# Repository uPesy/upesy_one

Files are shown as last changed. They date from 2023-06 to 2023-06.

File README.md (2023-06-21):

# uPesy One Board

In this repository you'll find Kicad 7.0 design files, BOM, schematics, 3D models for the uPesy One board. An Arduino UNO compatible board based on the ATMEGA328PB chip.

<p align="center">
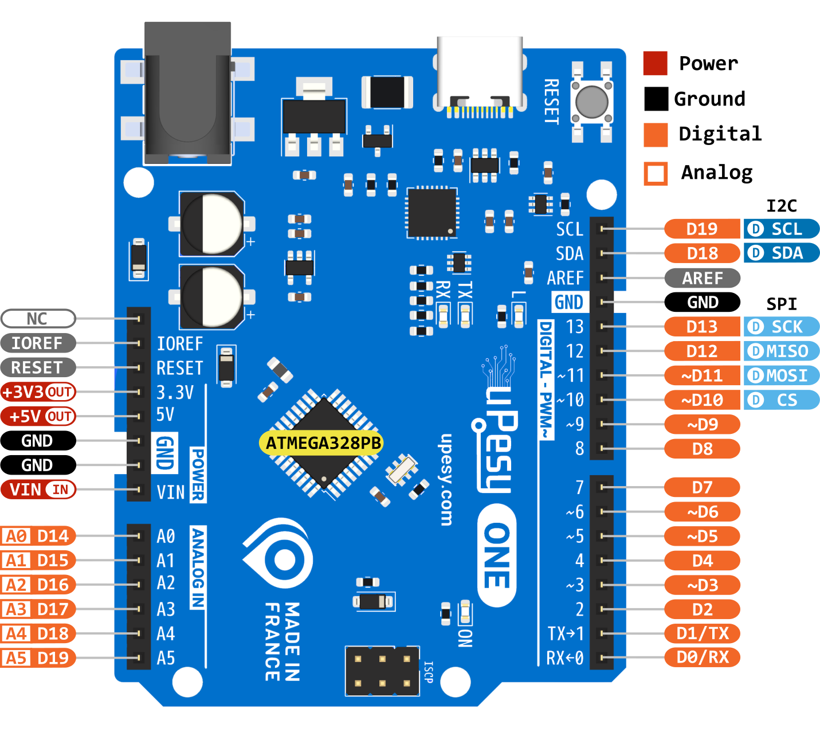
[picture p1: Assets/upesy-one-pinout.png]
  
</p>

## 🙏 Contribute

Feel free to suggest improvements and report any bugs you encounter by submitting a PR or an issue :)

## ⚖️ License

The uPesy One board files are licensed under the [Creative Commons CC-BY-SA 4.0 License](https://creativecommons.org/licenses/by-sa/4.0/legalcode).

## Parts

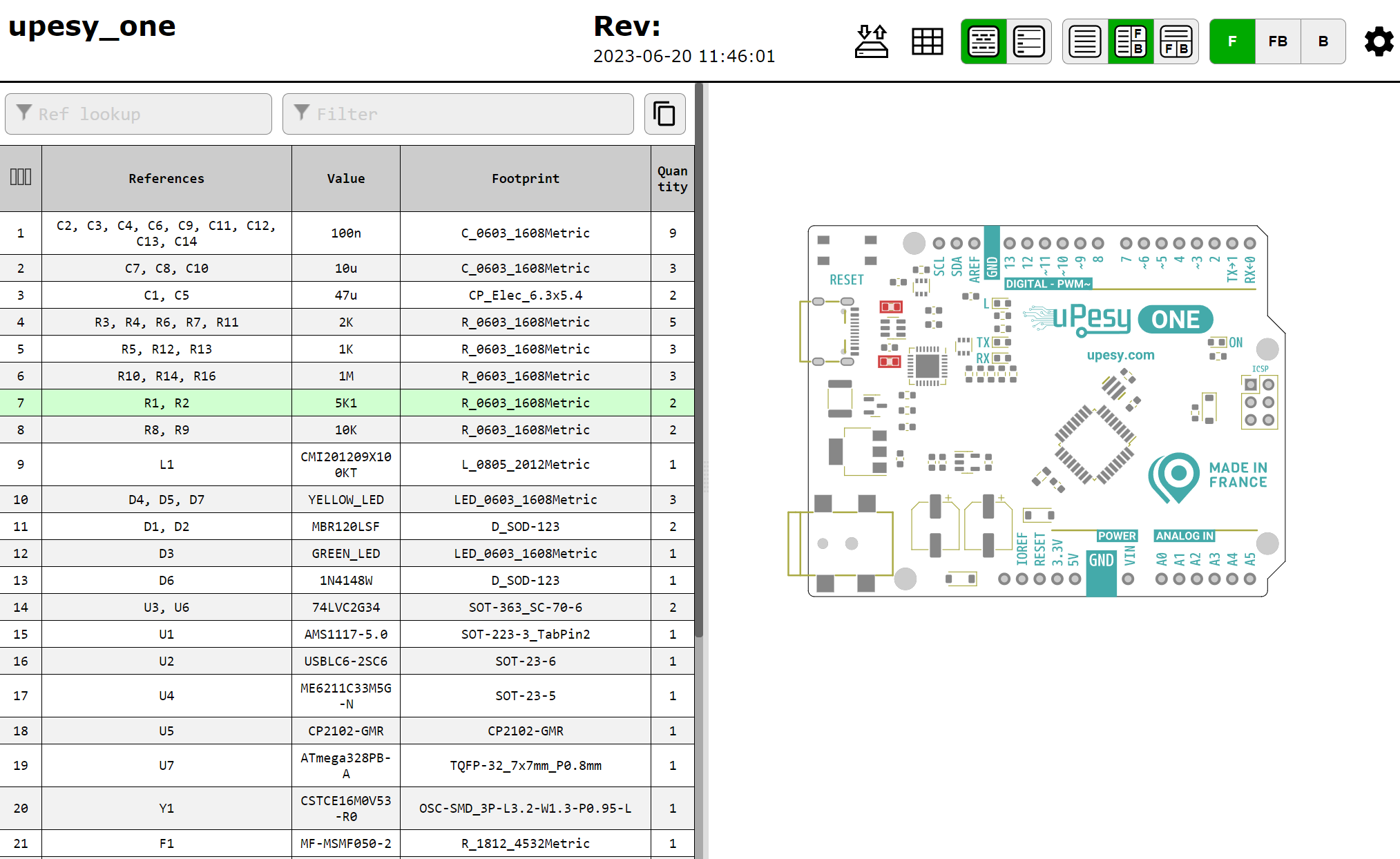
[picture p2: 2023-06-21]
Assets/screenshot_bom.PNG

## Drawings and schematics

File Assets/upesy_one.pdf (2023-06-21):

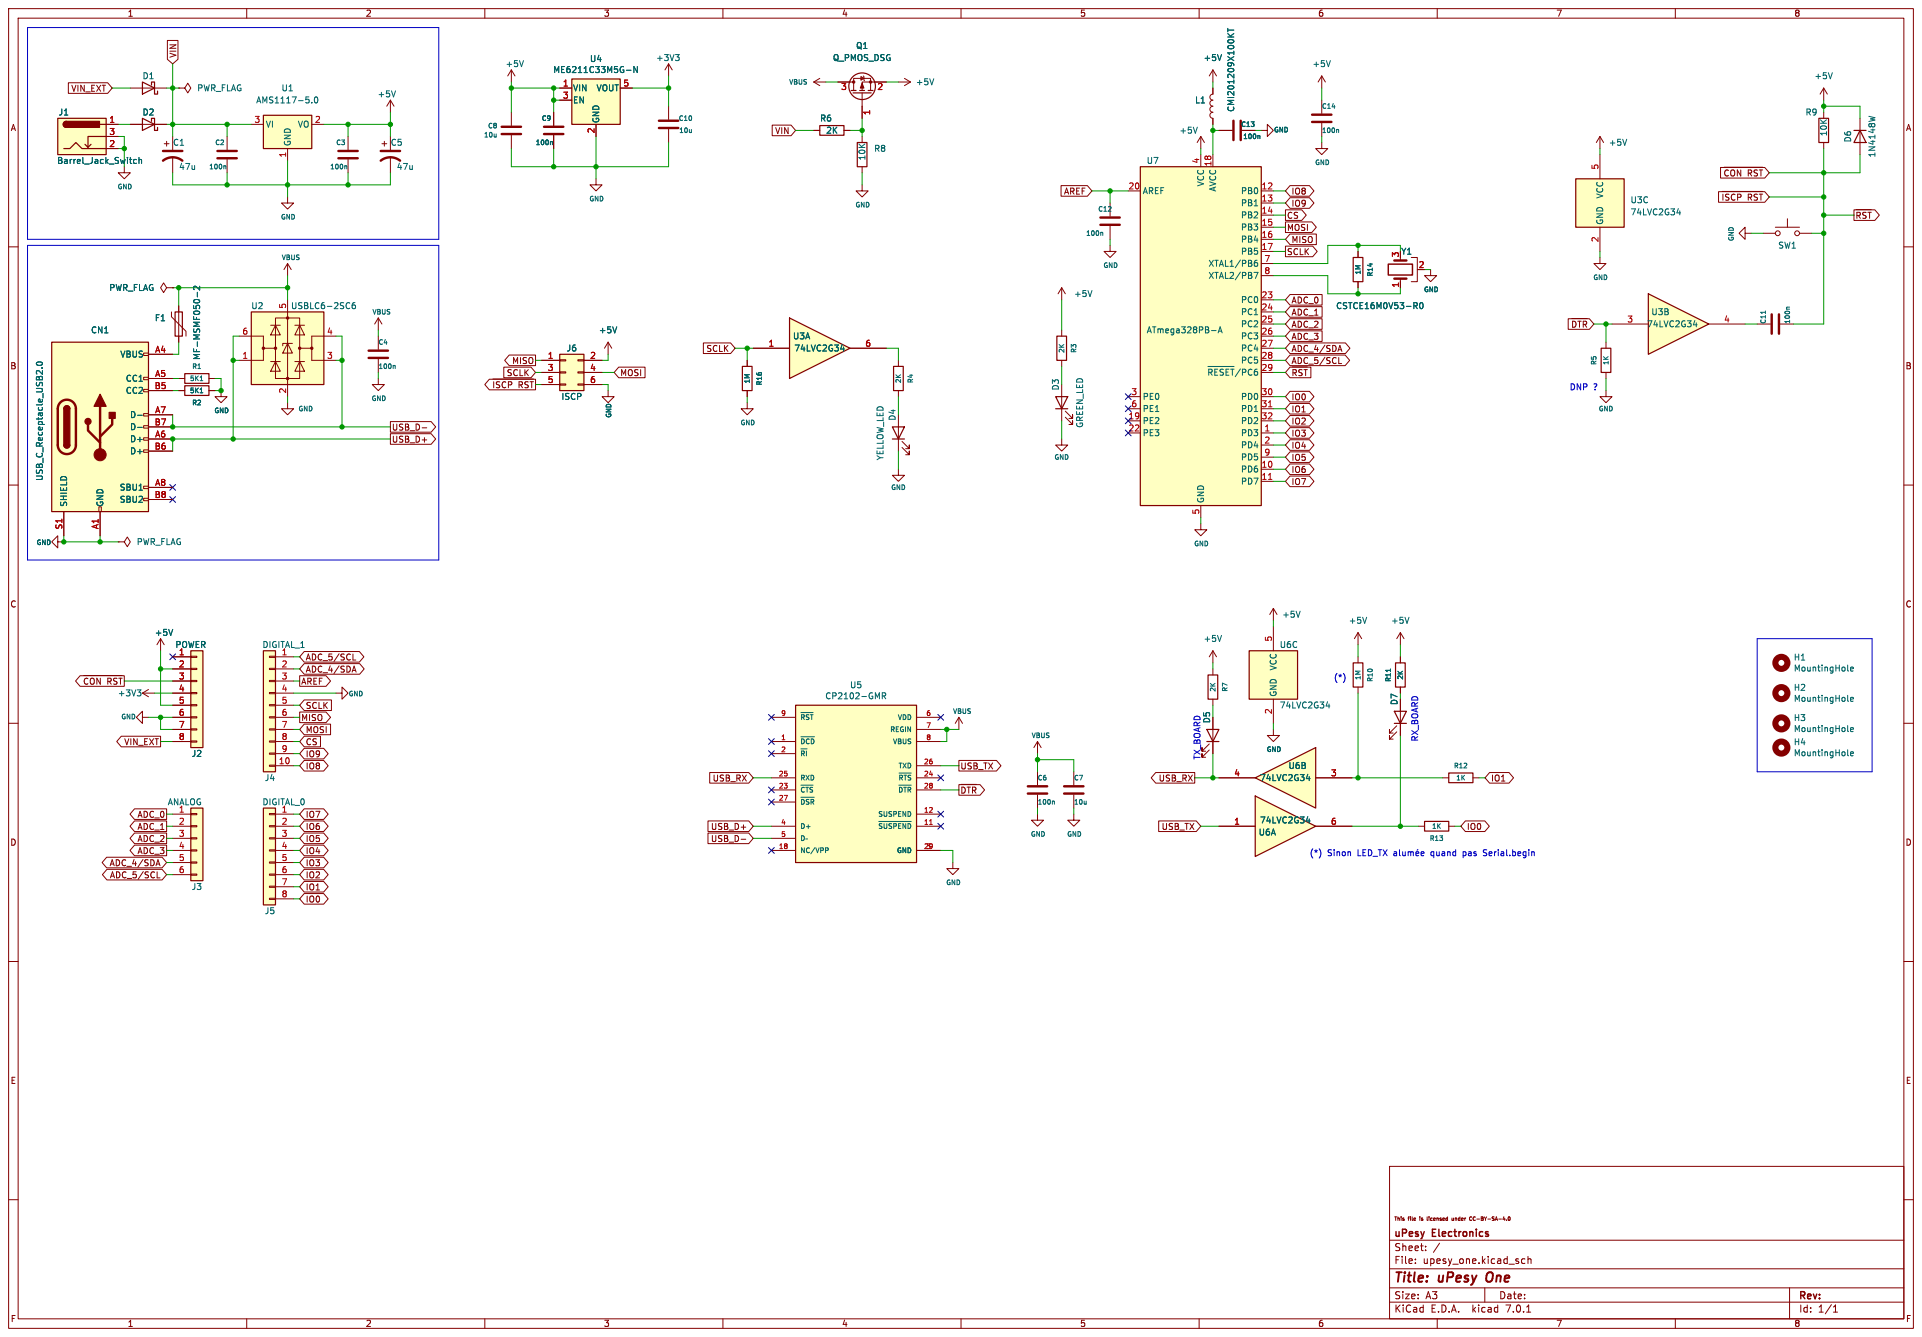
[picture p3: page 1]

(*) Sinon LED_TX þÿalumée quand pas Serial.begin

Id: 1/1 Title: uPesy One

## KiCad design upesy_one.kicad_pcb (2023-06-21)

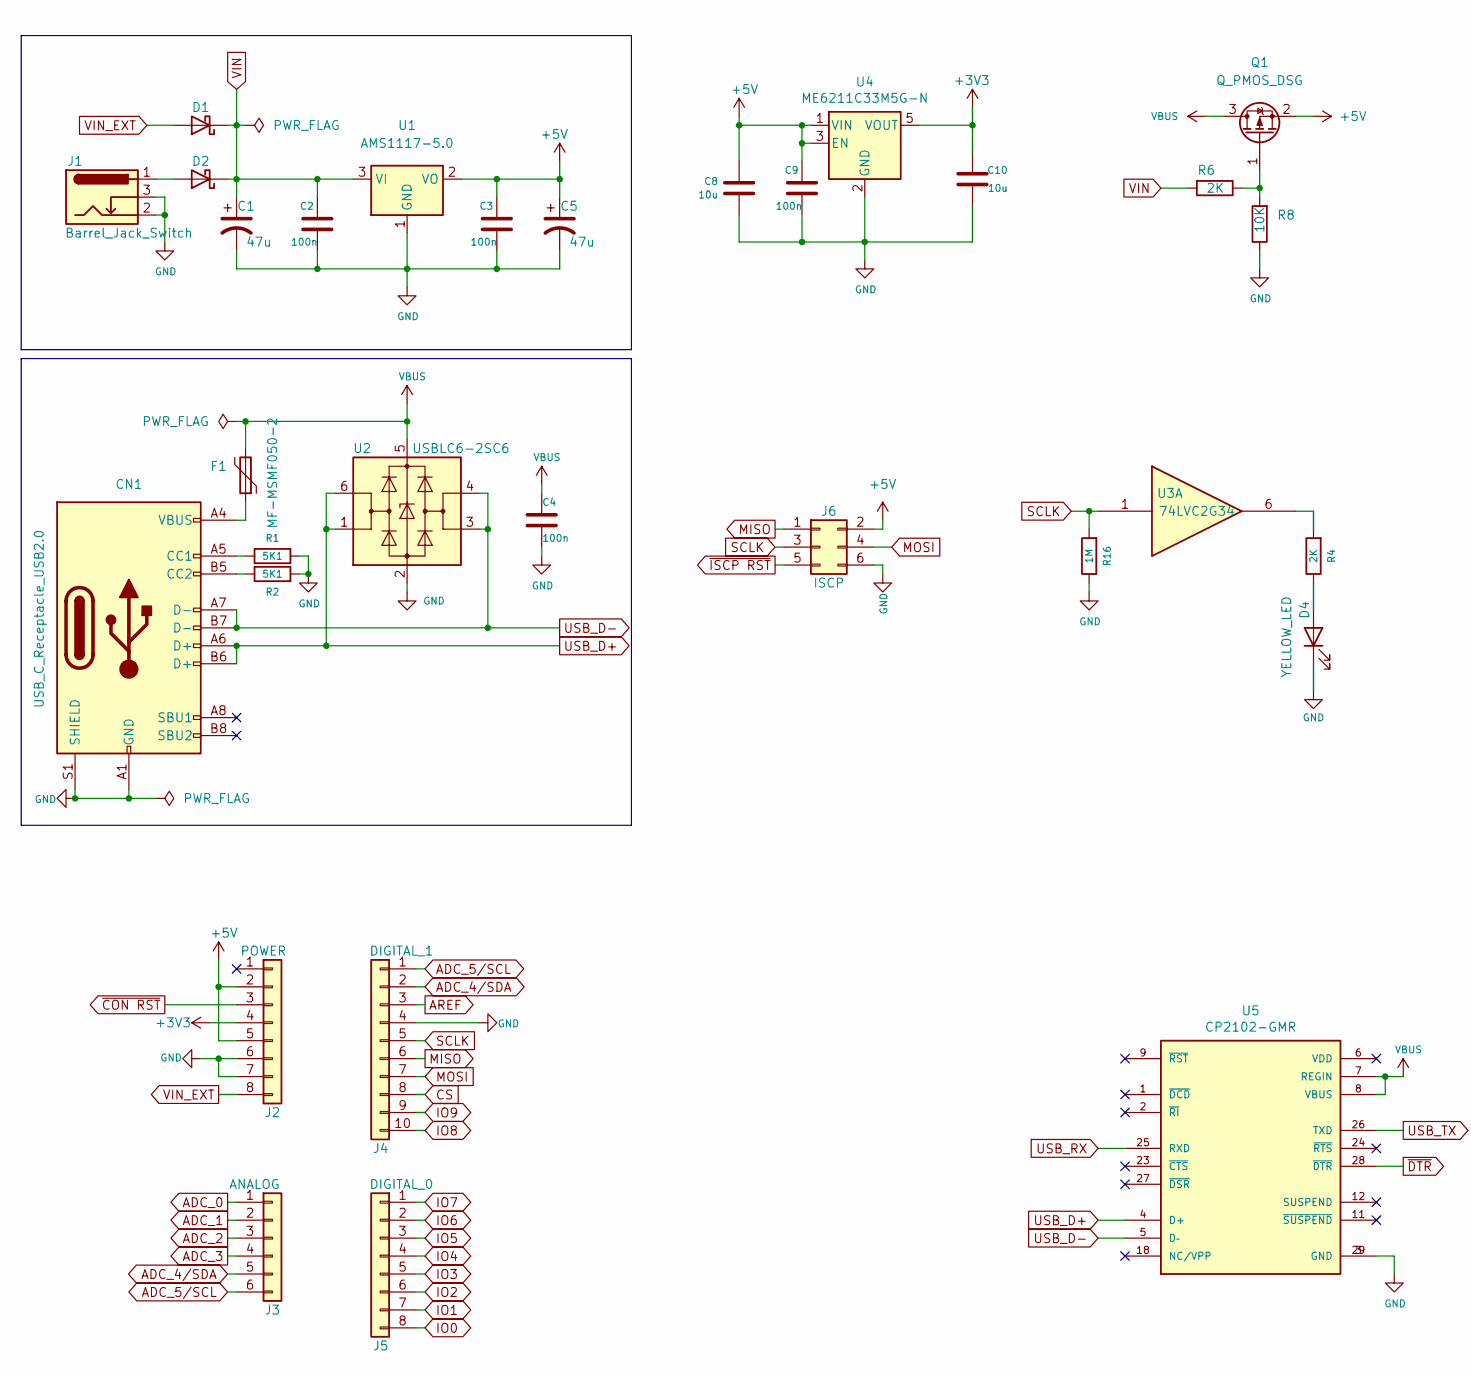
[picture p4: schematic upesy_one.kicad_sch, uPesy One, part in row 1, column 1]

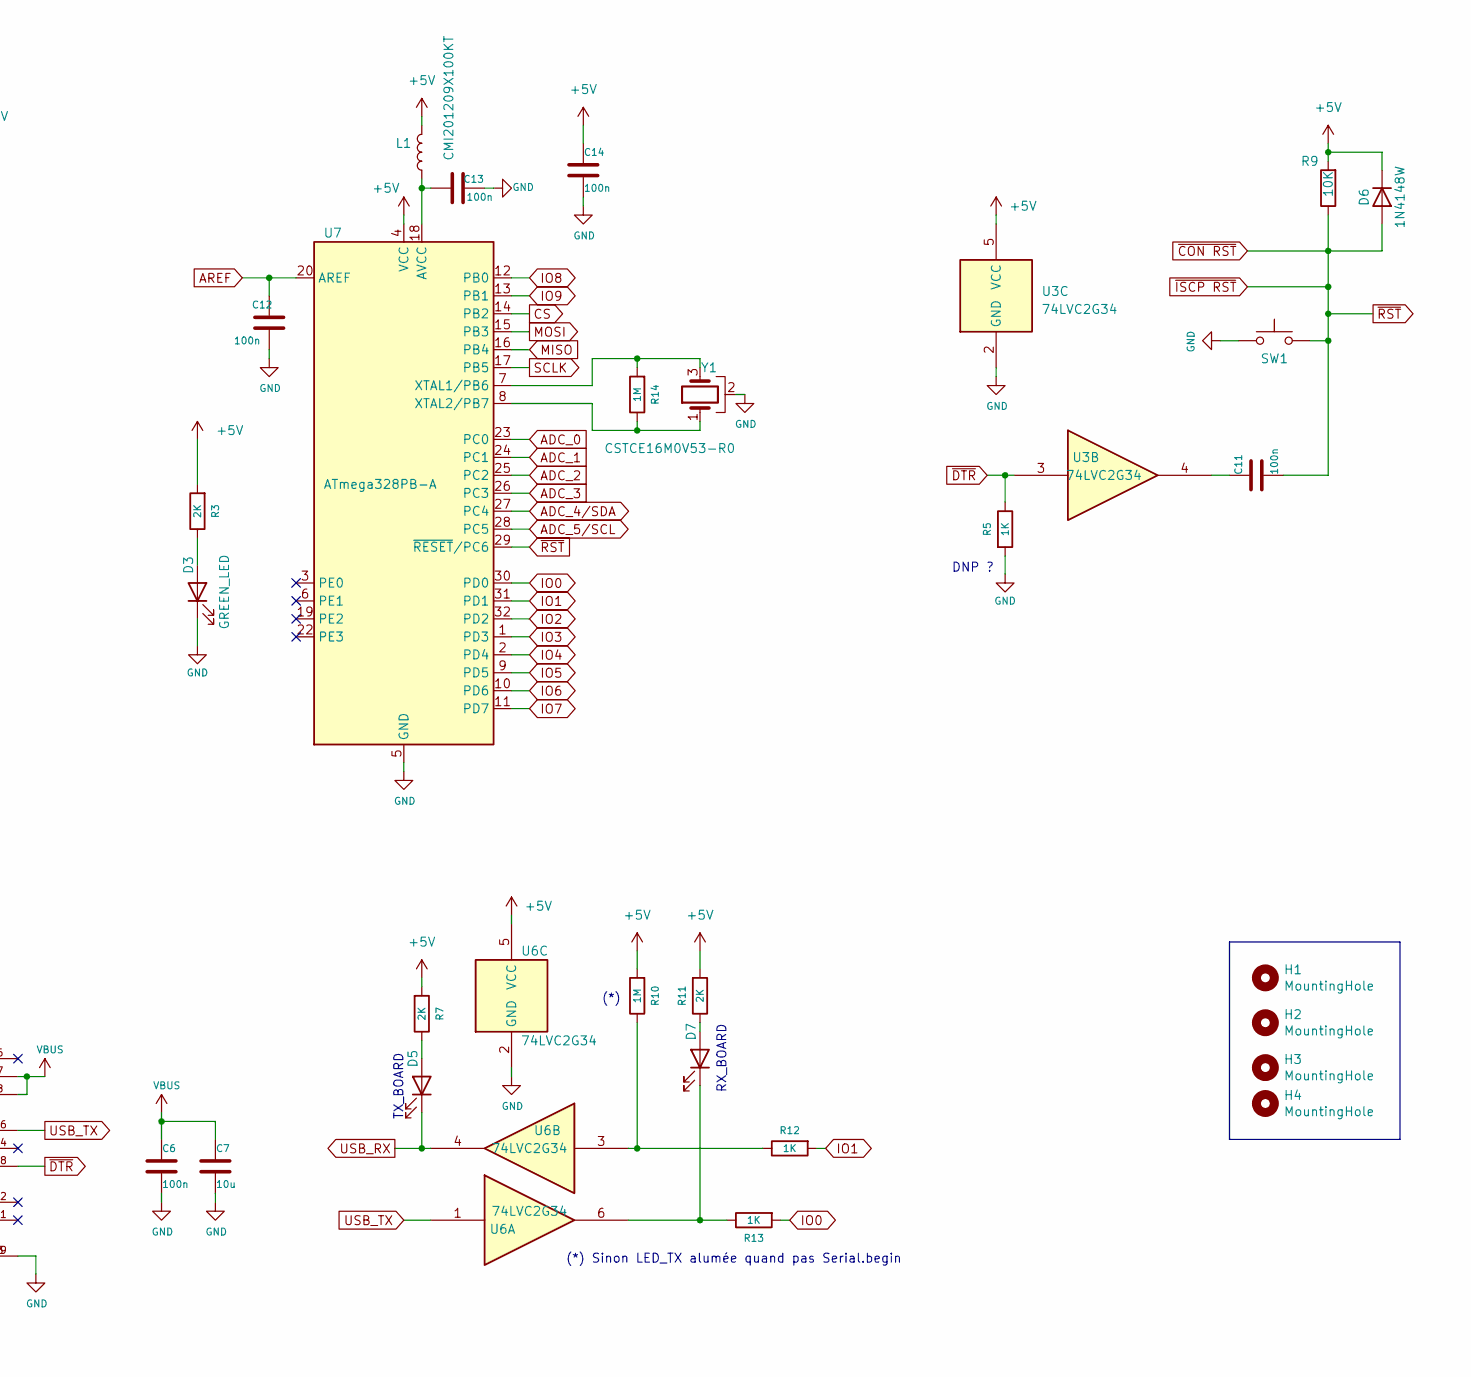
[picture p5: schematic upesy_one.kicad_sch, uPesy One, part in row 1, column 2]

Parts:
C1, C5: 47u; CP_Elec_6.3x5.4
C2, C3, C4, C6, C9, C11, C12, C13, C14: 100n; C_0603_1608Metric
C7, C8, C10: 10u; C_0603_1608Metric
CN1: USB_C_Receptacle_USB2.0; USB_C_C165948
D1, D2: MBR120LSF; D_SOD-123
D3: GREEN_LED; LED_0603_1608Metric
D4, D5, D7: YELLOW_LED; LED_0603_1608Metric
D6: 1N4148W; D_SOD-123
F1: MF-MSMF050-2; R_1812_4532Metric
H1, H2, H3, H4: MountingHole; MountingHole_3.2mm_M3_DIN965
J1: Barrel_Jack_Switch; DC-IN_DC050-T
J2: POWER; PinSocket_1x08_P2.54mm_Vertical
J3: ANALOG; PinSocket_1x06_P2.54mm_Vertical
J4: DIGITAL_1; PinSocket_1x10_P2.54mm_Vertical
J5: DIGITAL_0; PinSocket_1x08_P2.54mm_Vertical
J6: ISCP; PinHeader_2x03_P2.54mm_Vertical
L1: CMI201209X100KT; L_0805_2012Metric
Q1: Q_PMOS_DSG; SOT-23
R1, R2: 5K1; R_0603_1608Metric
R3, R4, R6, R7, R11: 2K; R_0603_1608Metric
R5, R12, R13: 1K; R_0603_1608Metric
R8, R9: 10K; R_0603_1608Metric
R10, R14, R16: 1M; R_0603_1608Metric
SW1: SW_Push; KEY-SMD_4P-L4.5-W4.5-P3.00-LS6.9
U1: AMS1117-5.0; SOT-223-3_TabPin2
U2: USBLC6-2SC6; SOT-23-6
U3, U6: 74LVC2G34; SOT-363_SC-70-6
U4: ME6211C33M5G-N; SOT-23-5
U5: CP2102-GMR
U7: ATmega328PB-A; TQFP-32_7x7mm_P0.8mm
Y1: CSTCE16M0V53-R0; OSC-SMD_3P-L3.2-W1.3-P0.95-L

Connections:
+3V3: C10.2, J2.4, U4.5 (VOUT)
+5V: C3.1, C5.1, C8.2, C9.1, C14.2, D6.1 (K), J2.2, J2.5, J6.2, L1.2, Q1.2 (S), R3.2, R7.2, R9.2, R10.2, R11.2, U1.2 (VO), U3.5 (VCC), U4.1 (VIN), U4.3 (EN), U6.5 (VCC), U7.4 (VCC)
ADC_0: J3.1, U7.23 (PC0)
ADC_1: J3.2, U7.24 (PC1)
ADC_2: J3.3, U7.25 (PC2)
ADC_3: J3.4, U7.26 (PC3)
ADC_4/SDA: J3.5, J4.2, U7.27 (PC4)
ADC_5/SCL: J3.6, J4.1, U7.28 (PC5)
AREF: C12.2, J4.3, U7.20 (AREF)
CS: J4.8, U7.14 (PB2)
GND: C1.2, C2.2, C3.2, C4.1, C5.2, C6.1, C7.2, C8.1, C9.2, C10.1, C12.1, C13.2, C14.1, CN1.A1 (GND), CN1.A12 (GND), CN1.S1 (SHIELD), D3.1 (K), D4.1 (K), J1.2, J1.3, J2.6, J2.7, J4.4, J6.6, R1.2, R2.2, R5.2, R8.1, R16.1, SW1.1, U1.1 (GND), U2.2 (GND), U3.2 (GND), U4.2 (GND), U5.3 (GND), U5.29 (GND), U6.2 (GND), U7.5 (GND), U7.21 (GND), Y1.2
IO0: J5.8, R13.2, U7.30 (PD0)
IO1: J5.7, R12.2, U7.31 (PD1)
IO2: J5.6, U7.32 (PD2)
IO3: J5.5, U7.1 (PD3)
IO4: J5.4, U7.2 (PD4)
IO5: J5.3, U7.9 (PD5)
IO6: J5.2, U7.10 (PD6)
IO7: J5.1, U7.11 (PD7)
IO8: J4.10, U7.12 (PB0)
IO9: J4.9, U7.13 (PB1)
MISO: J4.6, J6.1, U7.16 (PB4)
MOSI: J4.7, J6.4, U7.15 (PB3)
unnamed: C11.2, U3.4
unnamed: CN1.A5 (CC1), R1.1
unnamed: CN1.B5 (CC2), R2.1
unnamed: CN1.A4 (VBUS), CN1.A9 (VBUS), F1.1
unnamed: D2.2 (A), J1.1
unnamed: D3.2 (A), R3.1
unnamed: D4.2 (A), R4.1
unnamed: D5.2 (A), R7.1
unnamed: D7.2 (A), R11.1
unnamed: D7.1 (K), R13.1, U6.6
unnamed: Q1.1 (G), R6.1, R8.2
unnamed: R4.2, U3.6
unnamed: R10.1, R12.1, U6.3
unnamed: C13.1, L1.1, U7.18 (AVCC)
unnamed: R14.2, U7.7 (XTAL1/PB6), Y1.3
unnamed: R14.1, U7.8 (XTAL2/PB7), Y1.1
SCLK: J4.5, J6.3, R16.2, U3.1, U7.17 (PB5)
USB_D+: CN1.A6 (D+), CN1.B6 (D+), U2.1 (I/O1), U2.6 (I/O1), U5.4 (D+)
USB_D-: CN1.A7 (D-), CN1.B7 (D-), U2.3 (I/O2), U2.4 (I/O2), U5.5 (D–)
USB_RX: D5.1 (K), U5.25 (RXD), U6.4
USB_TX: U5.26 (TXD), U6.1
VBUS: C4.2, C6.2, C7.1, F1.2, Q1.3 (D), U2.5 (VBUS), U5.7 (REGIN), U5.8 (VBUS)
VIN: C1.1, C2.1, D1.1 (K), D2.1 (K), R6.2, U1.3 (VI)
VIN_EXT: D1.2 (A), J2.8
~CON RST: C11.1, D6.2 (A), J2.3, J6.5, R9.1, SW1.2, U7.29 (~RESET/PC6)
~DTR: R5.1, U3.3, U5.28 (~DTR)

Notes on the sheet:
TX_BOARD
(*) Sinon LED_TX alumée quand pas Serial.begin
RX_BOARD
(*)
DNP ?

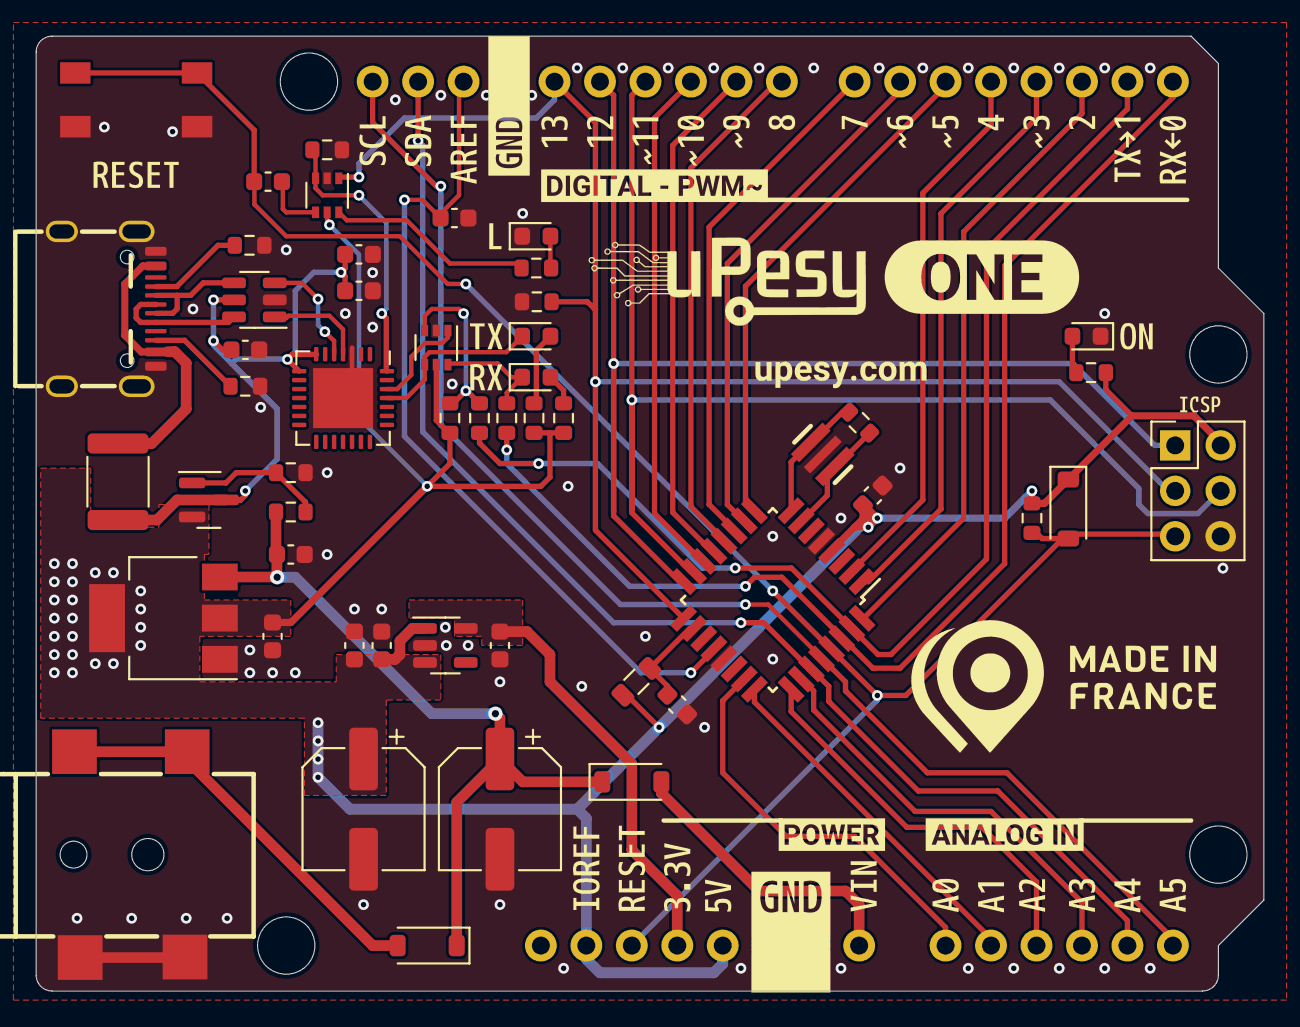
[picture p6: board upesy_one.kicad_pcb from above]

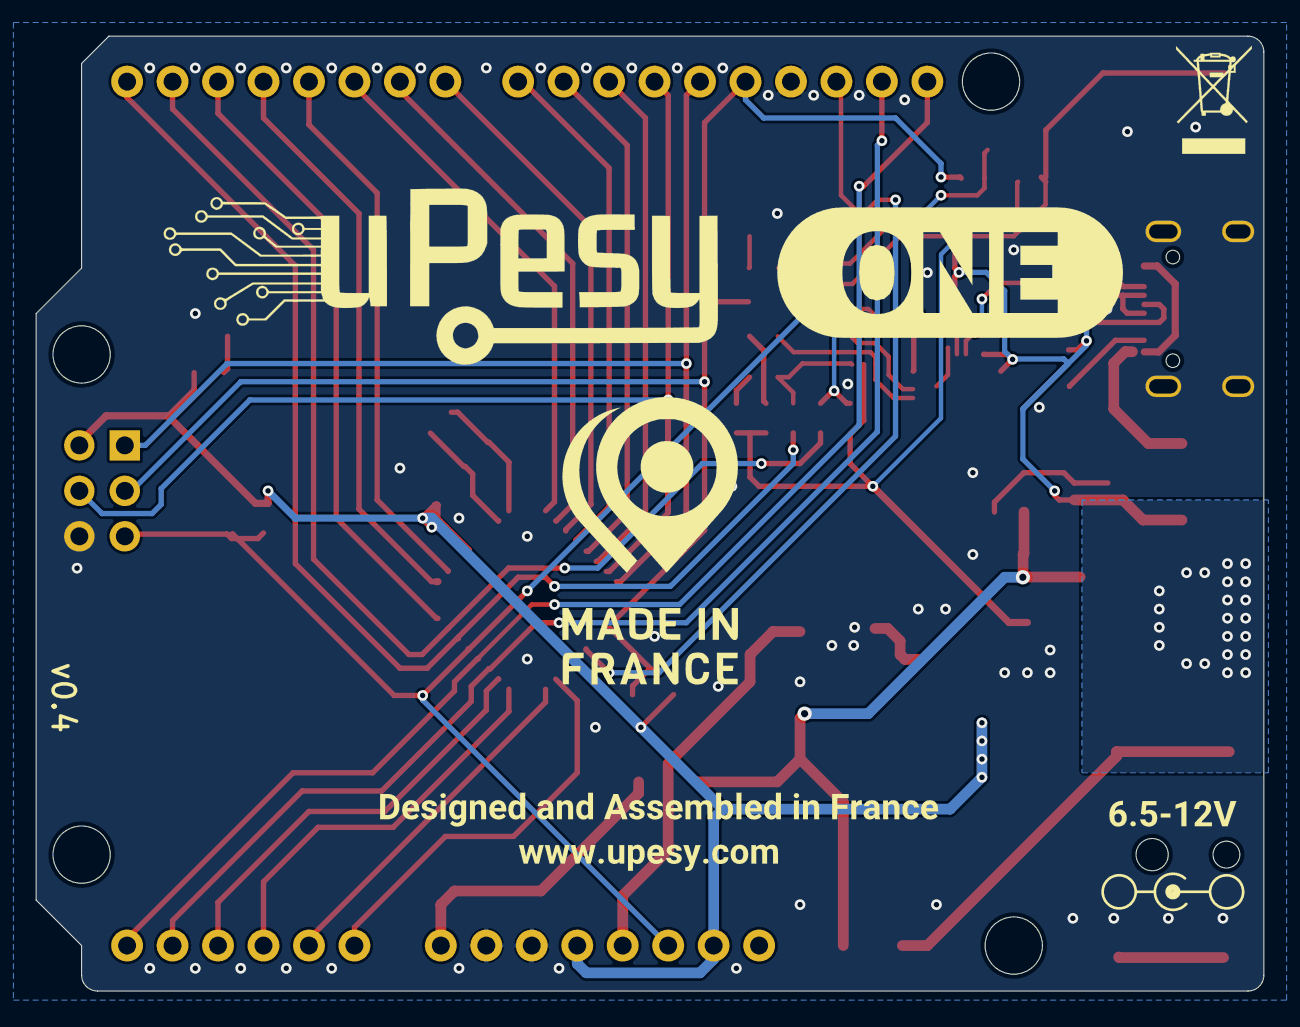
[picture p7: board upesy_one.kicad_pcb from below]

Board: 2 copper layers, 68.6 x 53.3 mm, 103 parts (3 on the bottom side), 49 nets.

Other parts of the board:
kibuzzard-63D7D00B: G***; kibuzzard-63D7D00B
kibuzzard-63D7D0BF: G***; kibuzzard-63D7D0BF
kibuzzard-63D7D0D3: G***; kibuzzard-63D7D0D3
kibuzzard-63D7D0E6: G***; kibuzzard-63D7D0E6
kibuzzard-63D7D0F3: G***; kibuzzard-63D7D0F3
kibuzzard-63D7D0F8: G***; kibuzzard-63D7D0F8
kibuzzard-63D7D1B7: G***; kibuzzard-63D7D1B7
kibuzzard-63D7D1D2: G***; kibuzzard-63D7D1D2
kibuzzard-63D7D01F: G***; kibuzzard-63D7D01F
kibuzzard-63D7D2C3: G***; kibuzzard-63D7D2C3
kibuzzard-63D7D2CB: G***; kibuzzard-63D7D2CB
kibuzzard-63D7D2D1: G***; kibuzzard-63D7D2D1
kibuzzard-63D7D2F8: G***; kibuzzard-63D7D2F8
kibuzzard-63D7D3AA: G***; kibuzzard-63D7D3AA
kibuzzard-63D7D3C4: G***; kibuzzard-63D7D3C4
kibuzzard-63D7D3CA: G***; kibuzzard-63D7D3CA
kibuzzard-63D7D04D: G***; kibuzzard-63D7D04D
kibuzzard-63D7D22A: G***; kibuzzard-63D7D22A
kibuzzard-63D7D32A: G***; kibuzzard-63D7D32A
kibuzzard-63D7D060: G***; kibuzzard-63D7D060
kibuzzard-63D7D69A: G***; kibuzzard-63D7D69A
kibuzzard-63D7D81F: G***; kibuzzard-63D7D81F
kibuzzard-63D7D84E: G***; kibuzzard-63D7D84E
kibuzzard-63D7D183: G***; kibuzzard-63D7D183
kibuzzard-63D7D199: G***; kibuzzard-63D7D199
kibuzzard-63D7D238: G***; kibuzzard-63D7D238
kibuzzard-63D7D324: G***; kibuzzard-63D7D324
kibuzzard-63D7D772: G***; kibuzzard-63D7D772
kibuzzard-63D7D845: G***; kibuzzard-63D7D845
kibuzzard-63D7D852: G***; kibuzzard-63D7D852
kibuzzard-63D7DA83: G***; kibuzzard-63D7DA83
kibuzzard-63D7DCFF: G***; kibuzzard-63D7DCFF
kibuzzard-63D7DD21: G***; kibuzzard-63D7DD21
kibuzzard-63D7DF6C: G***; kibuzzard-63D7DF6C
kibuzzard-63D7DFCE: G***; kibuzzard-63D7DFCE
kibuzzard-63DA85A6: G***; kibuzzard-63DA85A6
kibuzzard-63DA865D: G***; kibuzzard-63DA865D
kibuzzard-642FC67E: G***; kibuzzard-642FC67E
kibuzzard-642FC77B: G***; kibuzzard-642FC77B
kibuzzard-642FC531: G***; kibuzzard-642FC531
kibuzzard-6411EABE: G***; kibuzzard-6411EABE
kibuzzard-6464A8D9: G***; kibuzzard-6464A8D9
kibuzzard-64300AB8: G***; kibuzzard-64300AB8
kibuzzard-643009C9: G***; kibuzzard-643009C9

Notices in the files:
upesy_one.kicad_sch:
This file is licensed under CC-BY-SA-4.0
